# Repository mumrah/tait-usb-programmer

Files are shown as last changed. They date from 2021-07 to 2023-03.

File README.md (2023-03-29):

# Tait TM8100 USB programming module

This board is bespoke USB to UART converter for programming Tait TM8100 series radios. It connects to the front
end of a radio using a DB9 connector and provides a sturdy USB-B connector for interfacing with a PC. The board
uses the MCP2200 chip from Microchip.

The current version is [v2](https://github.com/mumrah/tait-usb-programmer/tree/main/v2)

## Usage

To use the programmer, two pieces of software are required:

1) MCP2200 Windows Driver https://ww1.microchip.com/downloads/en/DeviceDoc/MCP2221_Windows_Driver_2021-02-22.zip
2) Tait TM8100 Programming Software (can be found in the [TARPN Tait documentation](http://tarpn.net/t/builder/tait_tm8105_notes/builders_radios_tait8105.html)).

If the MCP2200 driver link is dead, check the product page for a new link https://www.microchip.com/en-us/product/MCP2200 
and [file an issue](https://github.com/mumrah/tait-usb-programmer/issues) against this repository.

The board is designed to plug directly into the front panel of a TM810x radio. A USB-B to USB-A cable (such as a modern
printer cable) is then used to connect the programmer board into a PC. 

Once the board is plugged in and detected by Windows, check the Device Manager to determine which COM port
the programmer was registered as.

Device Manager

In the Tait software, under Tools -> Options, select the COM port that was found in the Device Manager

Tait COM Selection

At this point, you can either "Read the Radio" or "Interrogate the Radio" using the Tait software. Refer to the 
[TARPN Tait documentation](http://tarpn.net/t/builder/tait_tm8105_notes/builders_radios_tait8105.html) for more details
on programming specifics.

## Programming the Programmer

This section only applies if you are building your own programmer. Once assembled, the board must be configured using 
the [software from Microchip](https://www.microchip.com/en-us/product/MCP2200). This is needed to invert the UART rx/tx 
signal levels as required by the Tait radios. With newer versions of the board (v2 and later), LEDs can be enabled by 
selecting "Enable Tx/Rx LEDs"



## Action Shot

Here is a video of a v2 board reading from a Tait TM8105

https://user-images.githubusercontent.com/55116/129118886-56906c2b-b291-4ea8-aef9-7abf3eee217b.mov

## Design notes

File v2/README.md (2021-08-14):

# Aug 2021, v2

[OSHPark link](https://oshpark.com/shared_projects/BDVREM16)

Redesign of the board to use SSOP package and add two indicator LEDs. 

# BOM

Digi-Key part numbers.

* MCP2200 SSOP package, MCP2200-I/SS-ND
* DB9 socket, 609-5189-ND
* USB-B socket, UE27BC54130-ND
* C1, C4: 0.1µF ceramic capacitor, 56-1C10Z5U104M050B-ND
* Y1: 12MHz quartz crystal oscillator, 300-6027-ND
* C2, C3: 18-22pF ceramic capacitor, BC1004CT-ND
* R1: Any low value 1/8W resistor or a jumper wire
* R2: 10kΩ 1/8W resistor
* R3, R4: 1kΩ 1/8W resistor
* RX, TX: any suitable 3mm or 5mm LED

# Images





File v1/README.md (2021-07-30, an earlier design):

# Jun 2021, v1

[OSHPark link](https://oshpark.com/shared_projects/mvXPEa5Z)

First working version. I assembled one with only C2, C3, Y1, and R2 aside from the connectors and IC. 

C1, R1, and C4 can probably be omitted, but they are recommended per the datasheet.

Due to low stock of the SOIC version, the next revision will use the SSOP package.

# BOM

Digi-Key part numbers.

* MCP2200 SOIC package, MCP2200-I/SO-ND
* DB9 socket, 609-5189-ND
* USB-B socket, UE27BC54130-ND
* C1: 0.1µF ceramic capacitor, 56-1C10Z5U104M050B-ND
* Y1: 12MHz quartz crystal oscillator, 300-6027-ND
* C2, C3: 18pF ceramic capacitor, BC1004CT-ND
* R2: Any low value 1/8W resistor, possibly just a jumper wire
* R1: 1kΩ 1/8W resistor
* C4: 0.1µF ceramic capacitor, 56-1C10Z5U104M050B-ND

# Images





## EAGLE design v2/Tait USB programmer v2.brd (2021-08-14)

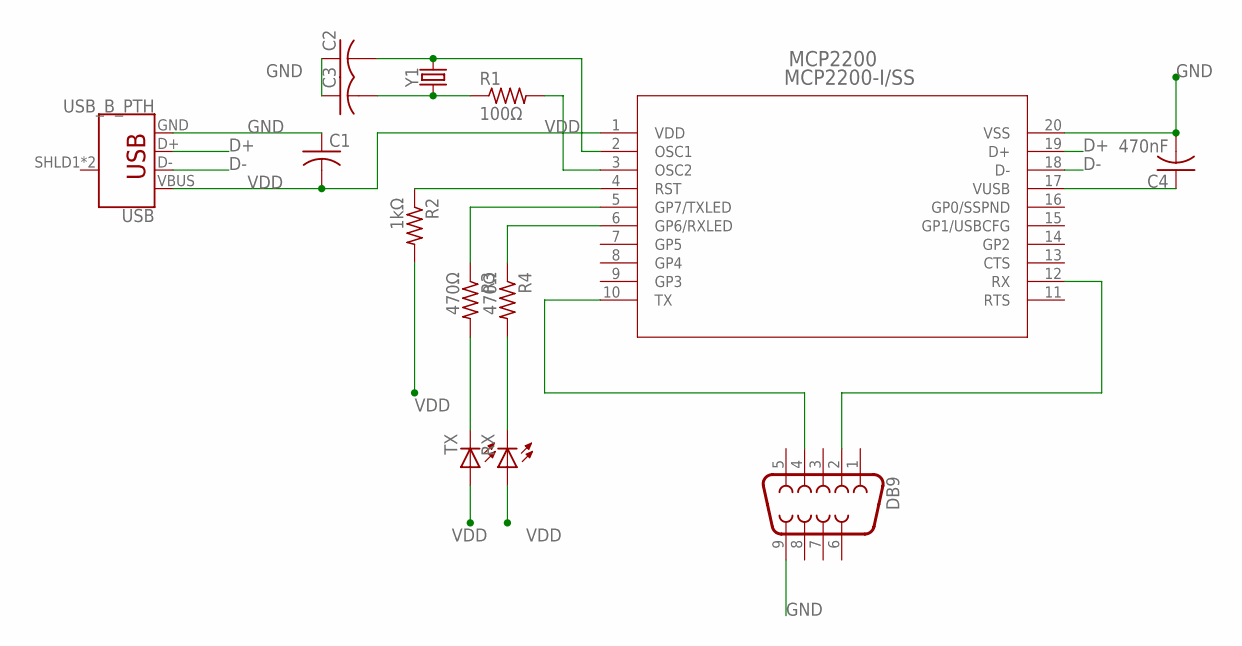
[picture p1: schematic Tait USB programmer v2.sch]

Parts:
C1: 0.1uF; C025-025X050
C2, C3: 22pF; C025-025X050
C4: 470nF; C025-025X050
DB9: DB9FEMALE; DB9
MCP2200: MCP2200-I/SS; SSOP20_MC_MCH
R1: 100Ω; 0204/7
R2: 1kΩ; 0204/7
R3, R4: 470Ω; 0204/7
RX: LED3MM
TX: LED3MM
USB: USB_B_PTH; USB-B-PTH
Y1: 12MHz; HC49U

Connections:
D+: MCP2200.19 (D+), USB.D+
D-: MCP2200.18 (D-), USB.D-
GND: C1.1, C2.1, C3.1, C4.2, DB9.9, MCP2200.20 (VSS), USB.GND
unnamed: C3.2, R1.1, Y1.1
unnamed: MCP2200.4 (RST), R2.1
unnamed: R3.2, TX.K (C)
unnamed: C2.2, MCP2200.2 (OSC1), Y1.2
unnamed: C4.1, MCP2200.17 (VUSB)
unnamed: DB9.2, MCP2200.12 (RX)
unnamed: DB9.4, MCP2200.10 (TX)
unnamed: R4.2, RX.K (C)
unnamed: MCP2200.6 (GP6/RXLED), R4.1
unnamed: MCP2200.3 (OSC2), R1.2
unnamed: MCP2200.5 (GP7/TXLED), R3.1
VDD: C1.2, MCP2200.1 (VDD), R2.2, RX.A, TX.A, USB.VBUS

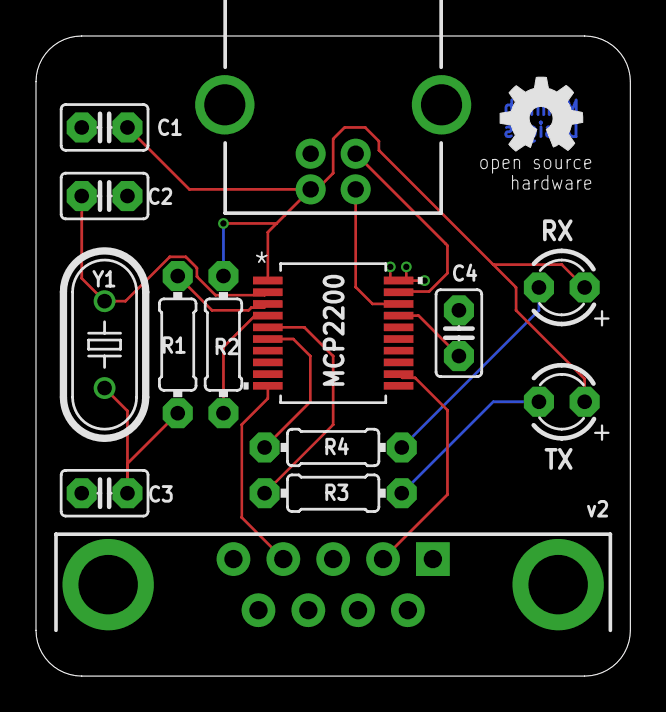
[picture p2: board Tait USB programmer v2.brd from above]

Board: 2 copper layers, 33.0 x 35.6 mm, 15 parts (0 on the bottom side), 15 nets.

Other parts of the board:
U$1: OSHW_5MM

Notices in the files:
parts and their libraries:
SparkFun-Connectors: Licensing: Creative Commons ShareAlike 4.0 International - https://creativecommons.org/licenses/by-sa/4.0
